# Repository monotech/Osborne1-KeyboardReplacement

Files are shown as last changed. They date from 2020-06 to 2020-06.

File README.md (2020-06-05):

# Osborne1-KeyboardReplacement
Replacement keyboard using Cherry MX switches, for if your Osborne 1 keyboard had a bad membrane like mine.

I think there are some Osborne 1 keyboards that are a different layout, which this may not work with.

If your Osborne 1 is like mine, I need an ISO '3' number-row key with £ sign instead of #. I think this comes down to the ROM in your system.

This is a slightly advanced project to mount to the original enclosure. You must:
- Shorten the original 8-32 hex spacers to about half, or buy the replacements in the BoM.
- Shorten the original 8-32 bolts to about 4.5mm thread length, or buy replacements.
- Figure out how to stop the PCB flexing in the middle. Two holes on the PCB are provided to add additional spacers and bolts for the easiest method (drill 2 holes in the original metal faceplate for this). If you wish to not deface the original plate, you will need to fashion something to sit behind the keyboard PCB in the enclosure.

BoM:
- PCB
- 69 x Cherry-MX-compatible keycaps
- 68 x Cherry MX-compatible PCB-mount switches (Cherry MX1A-11NW)
- 1 x Cherry MX Lock switch (Cherry MX1A-31NW)
- 1 x Cherry MX stabiliser kit for 2u-2.75u (Cherry G99-0742)
- 1 x Cherry MX stabiliser kit for 8u-10u (Cherry G99-0744)
- 1 x 2x10-pin 2.54mm vertical locking IDC connector (TE 5499206-4)
- 4 x 3/8" long 8-32 hex spacer (RAF 2102-832-AL)
- 4 x 3/16" threaded-length 8-32 bolts
- 2 x 3/8" long hex spacers (I used M3 threaded) (only used for my method of mounting, involving drilling 2 holes in the front plate)

Notes:
- I recommend Cherry MX Black, as it's closest to the original feel (it feels better imo).
- Cherry MX Lock are obsolete and hard to find. You can replace with another latching switch in a bodgy manner if you can't find one. I found a panel-mount one, and used epoxy for strength since it didn't have the PCB-mounting nubs.
- 9 of the keycaps need to be custom-made, the rest are from standard ANSI and ISO sets. I used the DSA Dolch set from Signature Plastics as my base.

Standard keycaps:
- Letters (26 keys)
- Esc and arrow keys (5 keys)
- Tab (1.5u)
- Numpad 1-9 and . (10 keys)
- Number row, from 1 to = (12 keys) (ANSI or ISO '3' key depending on your ROM)
- Punctuation ( < > ? : " ) (5 keys)
- Backslash/pipe key (1u) (from ISO set)
- Spacebar (8u) (I used their DSA-profile black one)

Custom keycaps:
- Square bracket key (1u)
- Return (2u)
- 2 x Shift (1.5u)
- Alpha Lock (1u)
- Enter (1u)
- Numpad 0 (1u)
- Ctrl (1u)

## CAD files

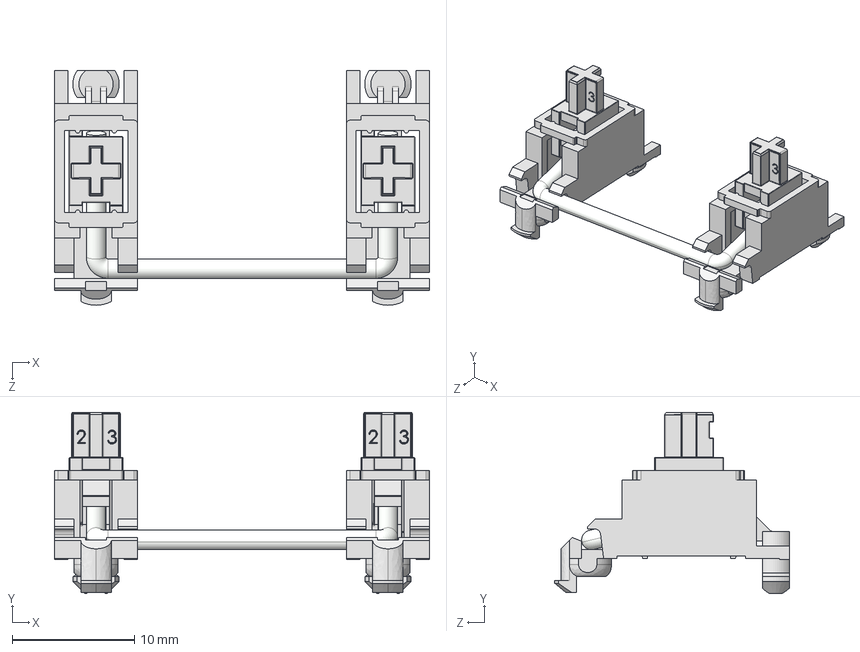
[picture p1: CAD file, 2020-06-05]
Stabilizer - close.STEP
30.7 x 14.9 x 19.2 mm
mx Stabilizer base 16828 x 2
mx Stabilizer key 16828 x 2
metal stick 16828

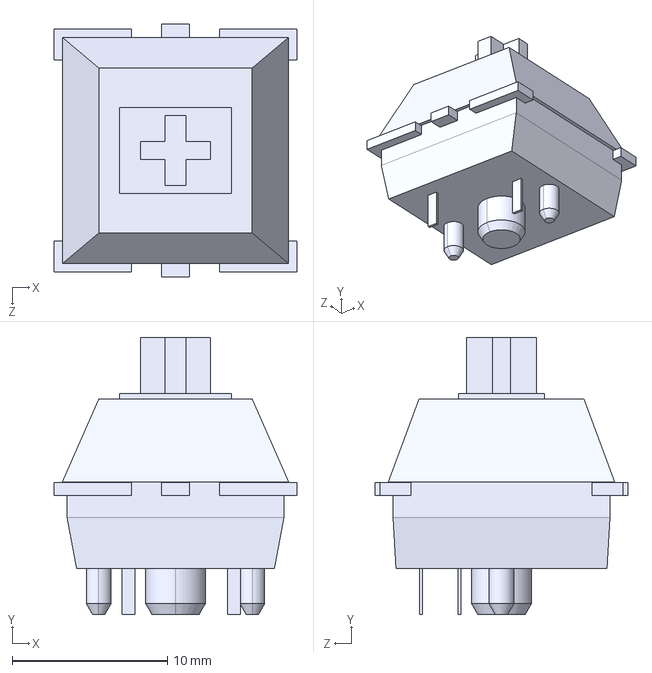
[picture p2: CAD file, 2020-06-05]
cherry mx.STEP
15.6 x 17.9 x 16.3 mm

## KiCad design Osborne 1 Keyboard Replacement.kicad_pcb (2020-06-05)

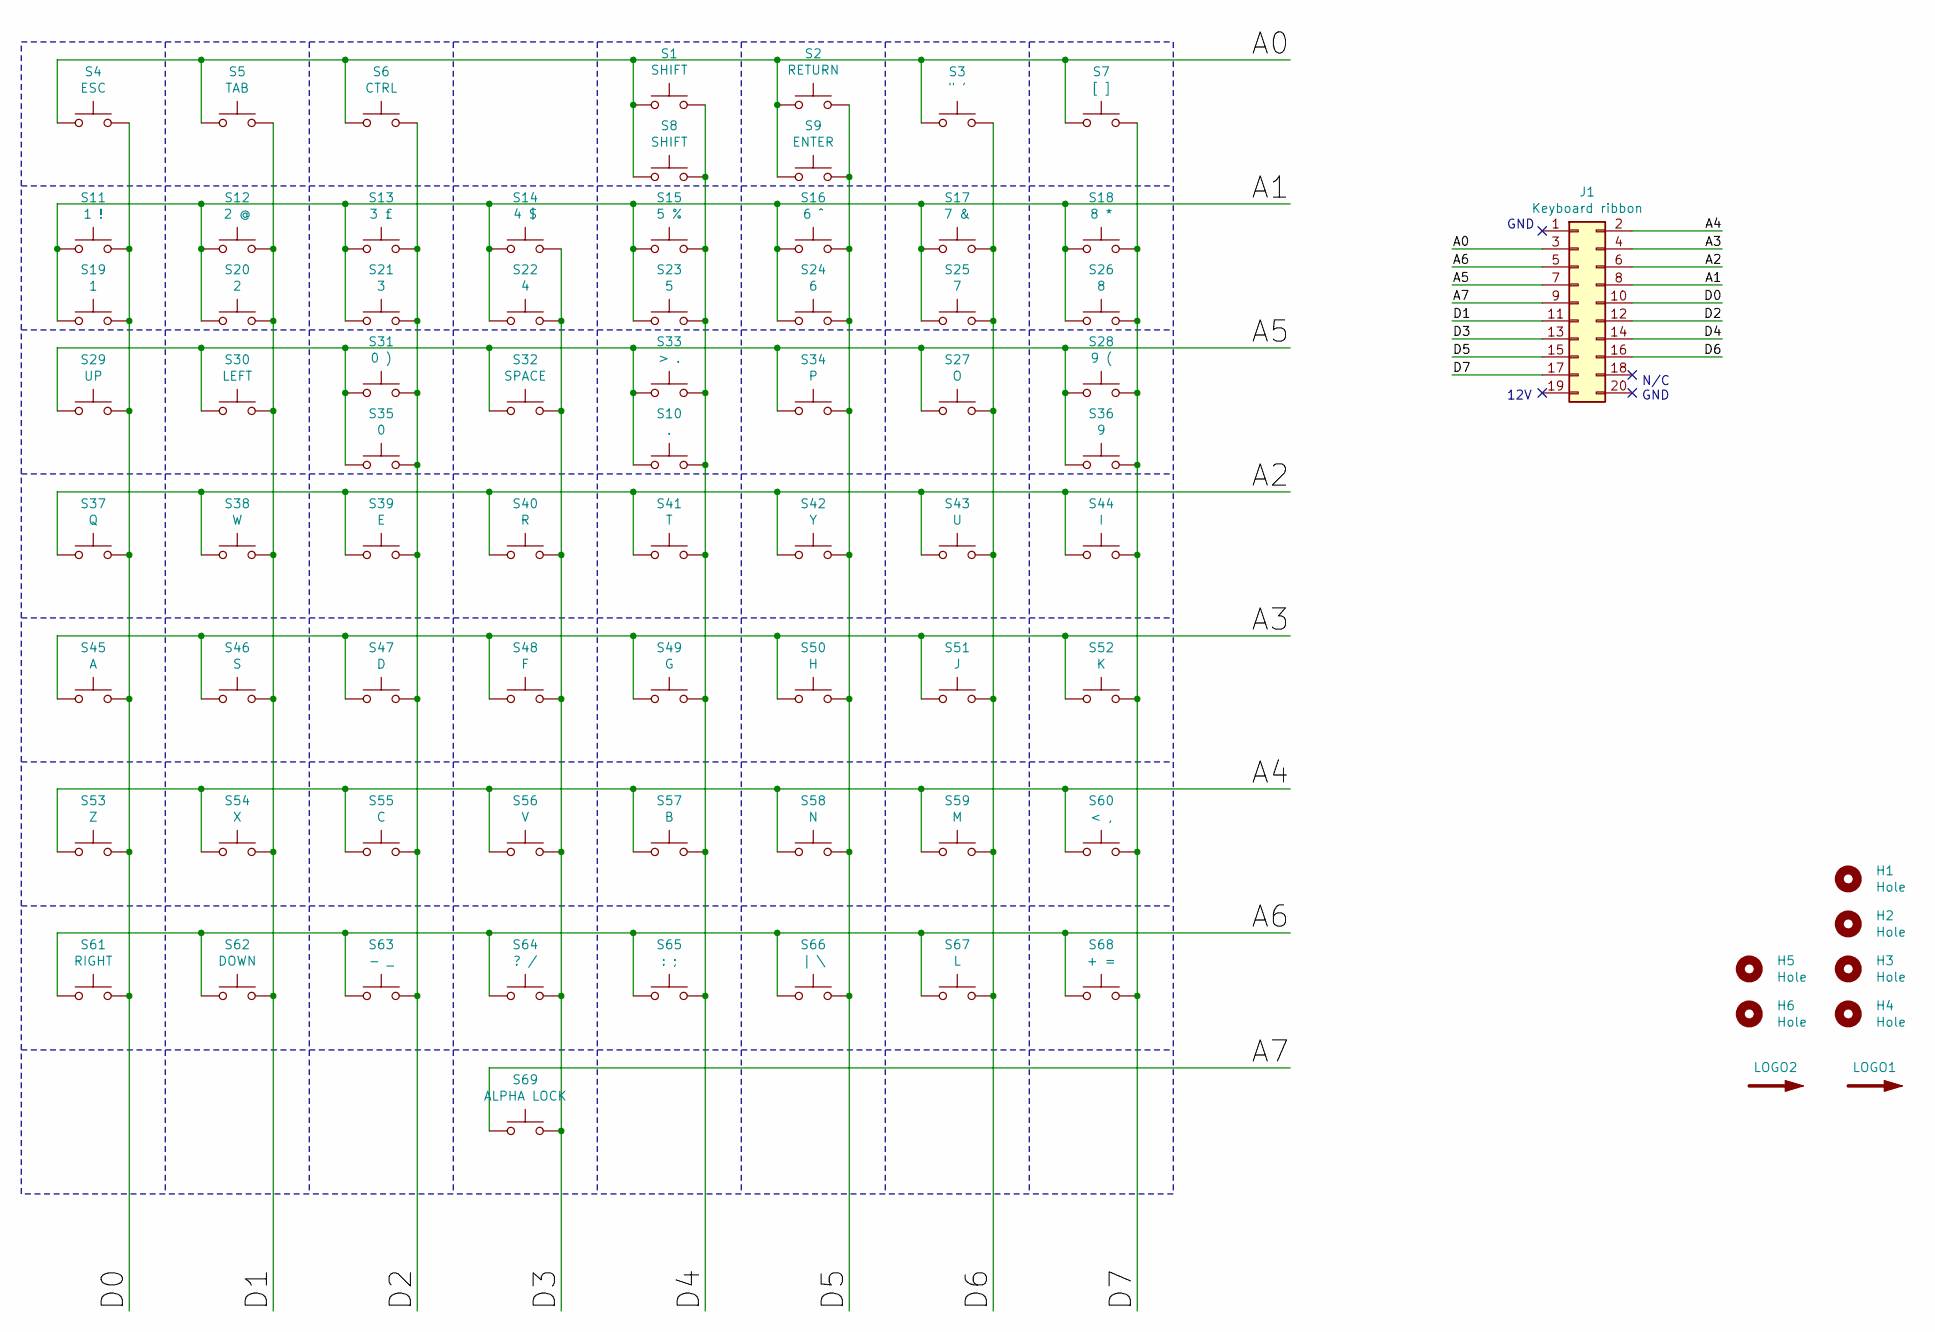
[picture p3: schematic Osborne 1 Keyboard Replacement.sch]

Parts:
H1, H2, H3, H4: Hole; MountingHole_4.3mm_M4
H5, H6: Hole; MountingHole_3.2mm_M3
J1: Keyboard ribbon; IDC-Header_2x10_P2.54mm_Vertical_Lock
LOGO1, LOGO2: SYM_Arrow_Large; Monotech Logo 18mm
S1, S8: SHIFT; SW_Cherry_MX_1.50u_PCB
S2: RETURN; SW_Cherry_MX_2.00u_PCB
S3: \" '; SW_Cherry_MX_1.00u_PCB
S4: ESC; SW_Cherry_MX_1.00u_PCB
S5: TAB; SW_Cherry_MX_1.50u_PCB
S6: CTRL; SW_Cherry_MX_1.00u_PCB
S7: [ ]; SW_Cherry_MX_1.00u_PCB
S9: ENTER; SW_Cherry_MX_1.00u_PCB
S10: .; SW_Cherry_MX_1.00u_PCB
S11: 1 !; SW_Cherry_MX_1.00u_PCB
S12: 2 @; SW_Cherry_MX_1.00u_PCB
S13: 3 £; SW_Cherry_MX_1.00u_PCB
S14: 4 $; SW_Cherry_MX_1.00u_PCB
S15: 5 %; SW_Cherry_MX_1.00u_PCB
S16: 6 ^; SW_Cherry_MX_1.00u_PCB
S17: 7 &; SW_Cherry_MX_1.00u_PCB
S18: 8 *; SW_Cherry_MX_1.00u_PCB
S19: 1; SW_Cherry_MX_1.00u_PCB
S20: 2; SW_Cherry_MX_1.00u_PCB
S21: 3; SW_Cherry_MX_1.00u_PCB
S22: 4; SW_Cherry_MX_1.00u_PCB
S23: 5; SW_Cherry_MX_1.00u_PCB
S24: 6; SW_Cherry_MX_1.00u_PCB
S25: 7; SW_Cherry_MX_1.00u_PCB
S26: 8; SW_Cherry_MX_1.00u_PCB
S27: O; SW_Cherry_MX_1.00u_PCB
S28: 9 (; SW_Cherry_MX_1.00u_PCB
S29: UP; SW_Cherry_MX_1.00u_PCB
S30: LEFT; SW_Cherry_MX_1.00u_PCB
S31: 0 ); SW_Cherry_MX_1.00u_PCB
S32: SPACE; SW_Cherry_MX_8u_PCB
S33: > .; SW_Cherry_MX_1.00u_PCB
S34: P; SW_Cherry_MX_1.00u_PCB
S35: 0; SW_Cherry_MX_1.00u_PCB
S36: 9; SW_Cherry_MX_1.00u_PCB
S37: Q; SW_Cherry_MX_1.00u_PCB
S38: W; SW_Cherry_MX_1.00u_PCB
S39: E; SW_Cherry_MX_1.00u_PCB
S40: R; SW_Cherry_MX_1.00u_PCB
S41: T; SW_Cherry_MX_1.00u_PCB
S42: Y; SW_Cherry_MX_1.00u_PCB
S43: U; SW_Cherry_MX_1.00u_PCB
S44: I; SW_Cherry_MX_1.00u_PCB
S45: A; SW_Cherry_MX_1.00u_PCB
S46: S; SW_Cherry_MX_1.00u_PCB
S47: D; SW_Cherry_MX_1.00u_PCB
S48: F; SW_Cherry_MX_1.00u_PCB
S49: G; SW_Cherry_MX_1.00u_PCB
S50: H; SW_Cherry_MX_1.00u_PCB
S51: J; SW_Cherry_MX_1.00u_PCB
S52: K; SW_Cherry_MX_1.00u_PCB
S53: Z; SW_Cherry_MX_1.00u_PCB
S54: X; SW_Cherry_MX_1.00u_PCB
S55: C; SW_Cherry_MX_1.00u_PCB
S56: V; SW_Cherry_MX_1.00u_PCB
S57: B; SW_Cherry_MX_1.00u_PCB
S58: N; SW_Cherry_MX_1.00u_PCB
S59: M; SW_Cherry_MX_1.00u_PCB
S60: < ,; SW_Cherry_MX_1.00u_PCB
S61: RIGHT; SW_Cherry_MX_1.00u_PCB
S62: DOWN; SW_Cherry_MX_1.00u_PCB
S63: - _; SW_Cherry_MX_1.00u_PCB
S64: ? /; SW_Cherry_MX_1.00u_PCB
S65: : ;; SW_Cherry_MX_1.00u_PCB
S66: | \\; SW_Cherry_MX_1.00u_PCB
S67: L; SW_Cherry_MX_1.00u_PCB
S68: + =; SW_Cherry_MX_1.00u_PCB
S69: ALPHA LOCK; SW_Cherry_MX_1.00u_PCB

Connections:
/A0: J1.3, S1.1, S2.1, S3.1, S4.1, S5.1, S6.1, S7.1, S8.1, S9.1
/A1: J1.8, S11.1, S12.1, S13.1, S14.1, S15.1, S16.1, S17.1, S18.1, S19.1, S20.1, S21.1, S22.1, S23.1, S24.1, S25.1, S26.1
/A2: J1.6, S37.1, S38.1, S39.1, S40.1, S41.1, S42.1, S43.1, S44.1
/A3: J1.4, S45.1, S46.1, S47.1, S48.1, S49.1, S50.1, S51.1, S52.1
/A4: J1.2, S53.1, S54.1, S55.1, S56.1, S57.1, S58.1, S59.1, S60.1
/A5: J1.7, S10.1, S27.1, S28.1, S29.1, S30.1, S31.1, S32.1, S33.1, S34.1, S35.1, S36.1
/A6: J1.5, S61.1, S62.1, S63.1, S64.1, S65.1, S66.1, S67.1, S68.1
/A7: J1.9, S69.1
/D0: J1.10, S4.2, S11.2, S19.2, S29.2, S37.2, S45.2, S53.2, S61.2
/D1: J1.11, S5.2, S12.2, S20.2, S30.2, S38.2, S46.2, S54.2, S62.2
/D2: J1.12, S6.2, S13.2, S21.2, S31.2, S35.2, S39.2, S47.2, S55.2, S63.2
/D3: J1.13, S14.2, S22.2, S32.2, S40.2, S48.2, S56.2, S64.2, S69.2
/D4: J1.14, S1.2, S8.2, S10.2, S15.2, S23.2, S33.2, S41.2, S49.2, S57.2, S65.2
/D5: J1.15, S2.2, S9.2, S16.2, S24.2, S34.2, S42.2, S50.2, S58.2, S66.2
/D6: J1.16, S3.2, S17.2, S25.2, S27.2, S43.2, S51.2, S59.2, S67.2
/D7: J1.17, S7.2, S18.2, S26.2, S28.2, S36.2, S44.2, S52.2, S60.2, S68.2

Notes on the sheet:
GND
12V
N/C GND

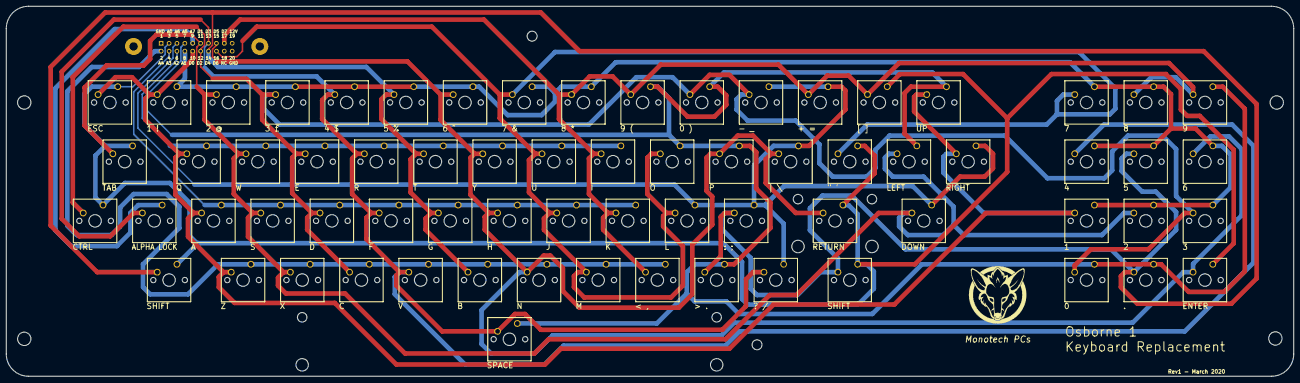
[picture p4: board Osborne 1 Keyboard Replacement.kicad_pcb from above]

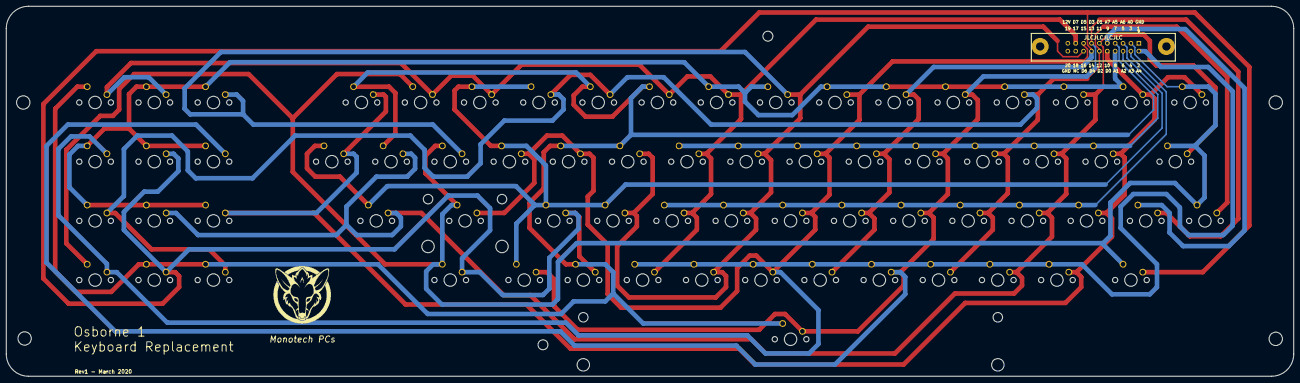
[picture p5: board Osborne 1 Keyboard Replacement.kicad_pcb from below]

Board: 2 copper layers, 414.3 x 119.1 mm, 78 parts (2 on the bottom side), 16 nets.
